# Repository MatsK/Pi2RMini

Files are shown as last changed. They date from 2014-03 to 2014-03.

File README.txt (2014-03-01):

Pi2RMini 
2013-2014 Logan Microelectronics

Small power switch for the Raspberry Pi. Free to use, modify, and distribute with proper attribution. This directory holds the current schematic and layout (Eagle v6.1.0), single layer PDF (not mirrored), code for ATTiny13 and Raspberry Pi, and older versions.

awjlogan@gmail.com
awjlogan.wordpress.com

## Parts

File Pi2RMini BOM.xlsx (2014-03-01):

Pi2RMini BOM file
Sch. # | Part | Package | Farnell Code | Price / 100 | Notes | Total ex. VAT | £2.241
C1 | 10u ceramic | 0805 | 1288204 | £0.066 |  | VAT | £0.448
C2 | 10u ceramic | 0805 | 1288204 | £0.066 |  | Total | £2.689
IC1 | ATtiny13 | SOIC8 | 1715519 | £0.360
IC2 | MCP1700 | SOT23 | 1296952 | £0.197 |  | Total parts
Q2 | 2N7002 | SOT23 | 2317616 | £0.020 |  | Total unique
Q1 | SQ2319ES | SOT23 | 1869886 | £0.320
USB | micro USB B | n/a | 1568026 | £0.480 | optional
LED1 | Bicolour LED | SOT23 | 2146479 | £0.174 | optional
R1 | 270R | 0805 | 2331788 | £0.006
R2 | 10K | 0805 | 2331808 | £0.006
R3 | 10K | 0805 | 2331808 | £0.006
R4 | 0R | jumper
R5 | 10K | 0805 | 2331808 | £0.006
R6 | 10K | 0805 | 2331808 | £0.006
R7 | 10K | 0805 | 2331808 | £0.006
R8 | 10K | 0805 | 2331823 | £0.006
ISP | 2x3 header | n/a | 1248132 | £0.230
FP | 2x3 header | n/a | 1248132 | £0.230
SW | switch | n/a | 9471731 | £0.038
R9 | 10K | 0805 | 2331808 | £0.006
D1 | LL4148 | miniMELF | 7355513 | £0.012 | optional

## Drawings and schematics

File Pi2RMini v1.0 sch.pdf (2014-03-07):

# 8 GND

A

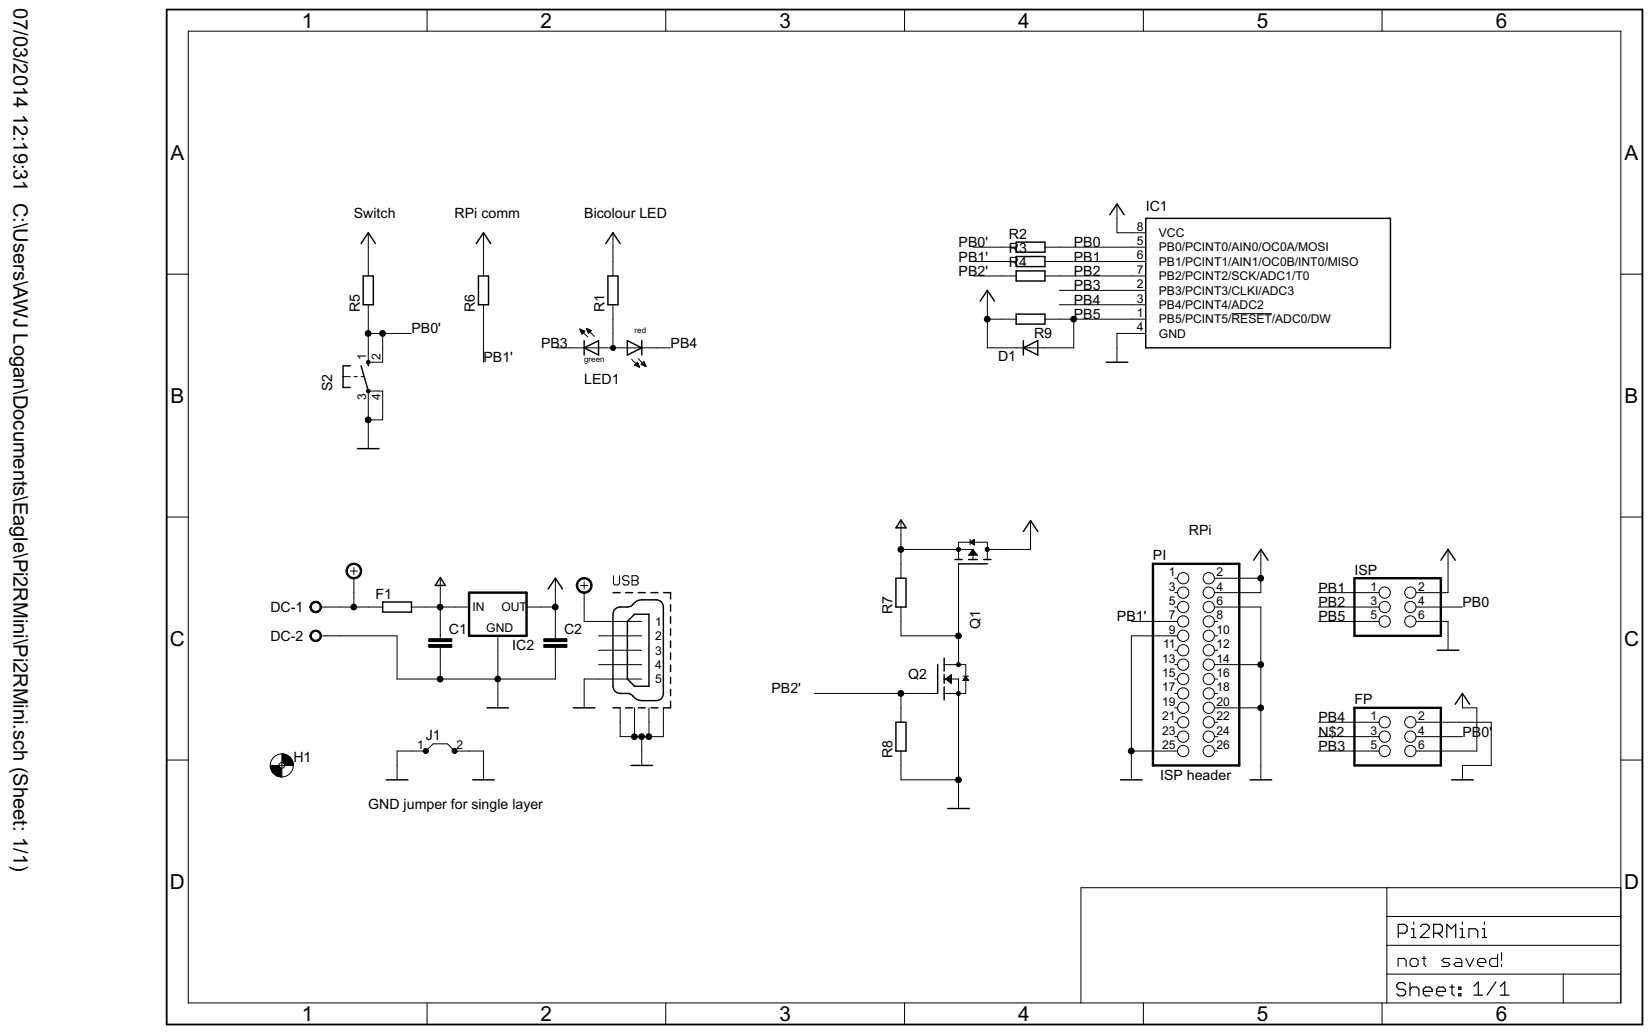
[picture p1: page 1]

07/03/2014 12:19:31 C:\Users\AWJ Logan\Documents\Eagle\Pi2RMini\Pi2RMini.sch (Sheet: 1/1)

GND jumper for single layer

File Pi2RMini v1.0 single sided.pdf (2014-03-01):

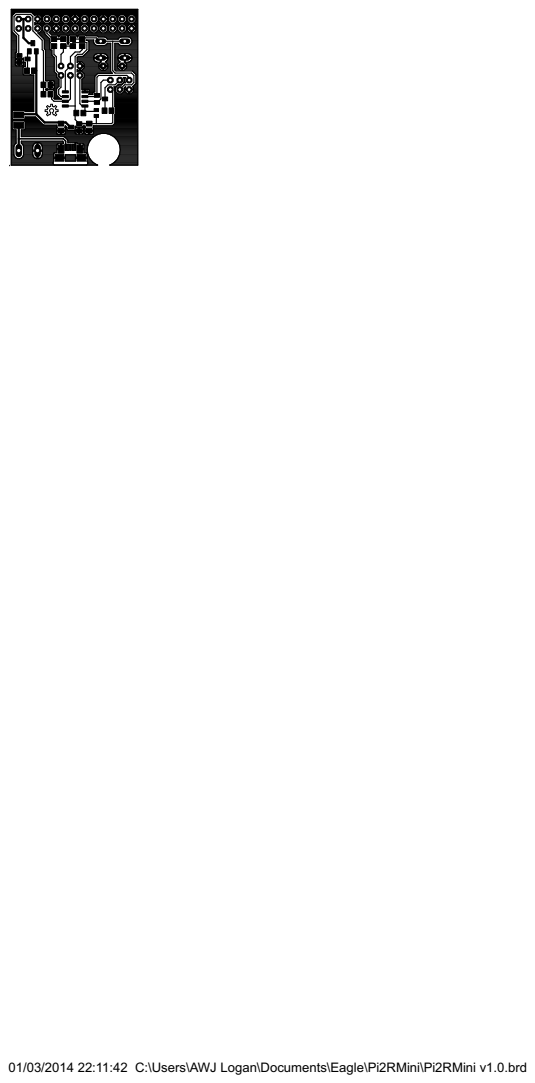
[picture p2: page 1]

01/03/2014 22:11:42 C:\Users\AWJ Logan\Documents\Eagle\Pi2RMini\Pi2RMini v1.0.brd

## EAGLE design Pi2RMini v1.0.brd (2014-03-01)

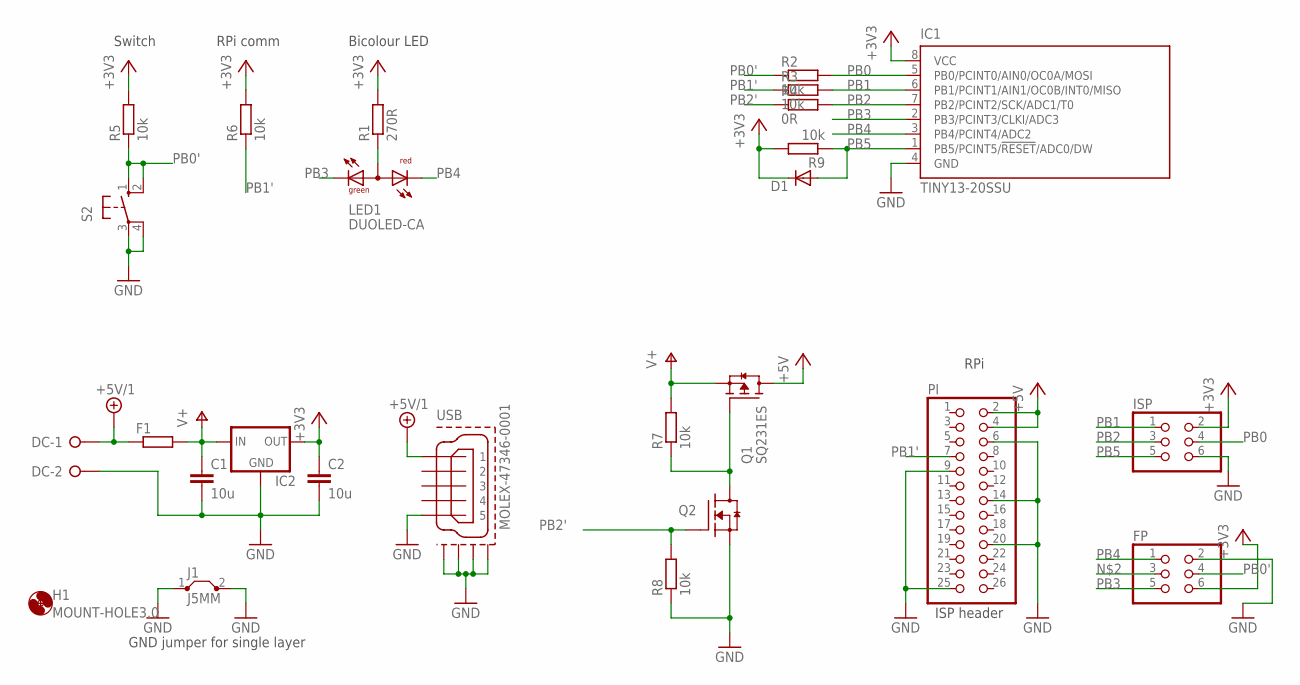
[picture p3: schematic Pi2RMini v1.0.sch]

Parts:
C1, C2: 10u; C0805
D1: DIODE-MICROMELF-R; MICROMELF-R
DC: W237-02P; W237-132
F1: R-EU_R1210; R1210
FP: PINHD-2X3; 2X03
H1: MOUNT-HOLE3.0; 3,0
IC1: TINY13-20SSU; 8S1
IC2: MCP1700TT; SOT-23
ISP: PINHD-2X3; 2X03
J1: J5MM; 05
LED1: DUOLED-CA; SOT-23
PI: PINHD-2X13; 2X13
Q1: SQ231ES; SOT-23
Q2: 2N7002; SOT-23
R1: 270R; R0805
R2, R3, R5, R6, R7, R8, R9: 10k; R0805
R4: 0R; R0805
S2: 10-XX; B3F-10XX
USB: MOLEX-47346-0001; MOLEX-47364-0001

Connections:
+3V3: C2.1, D1.C, FP.6, IC1.8 (VCC), IC2.2 (OUT), ISP.2, R1.2, R5.2, R6.2, R9.2
+5V: PI.2, PI.4, Q1.3 (D)
+5V/1: DC.1, F1.1, USB.1
GND: C1.2, C2.2, DC.2, FP.2, IC1.4 (GND), IC2.1 (GND), ISP.6, J1.1, J1.2, PI.6, PI.9, PI.14, PI.20, PI.25, Q2.2 (S), R8.1, S2.3, S2.4 (P1), USB.5, USB.GND1, USB.GND2, USB.GND3, USB.GND4
unnamed: FP.3, LED1.3 (A), R1.1
unnamed: Q1.1 (G), Q2.3 (D), R7.1
PB0: IC1.5 (PB0/PCINT0/AIN0/OC0A/MOSI), ISP.4, R2.2
PB0': FP.4, R2.1, R5.1, S2.1 (S), S2.2 (S1)
PB1: IC1.6 (PB1/PCINT1/AIN1/OC0B/INT0/MISO), ISP.1, R3.2
PB1': PI.7, R3.1, R6.1
PB2: IC1.7 (PB2/PCINT2/SCK/ADC1/T0), ISP.3, R4.2
PB2': Q2.1 (G), R4.1, R8.2
PB3: FP.5, IC1.2 (PB3/PCINT3/CLKI/ADC3), LED1.2 (CG)
PB4: FP.1, IC1.3 (PB4/PCINT4/ADC2), LED1.1 (CR)
PB5: D1.A, IC1.1 (PB5/PCINT5/!RESET!/ADC0/DW), ISP.5, R9.1
V+: C1.1, F1.2, IC2.3 (IN), Q1.2 (S), R7.2

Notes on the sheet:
Switch
RPi comm
Bicolour LED
GND jumper for single layer
ISP header
RPi

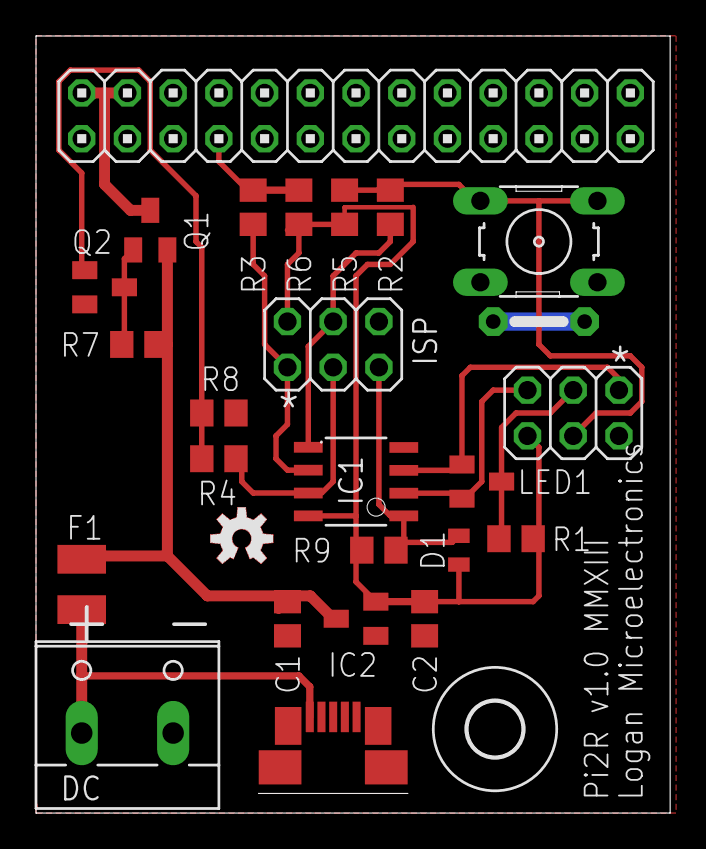
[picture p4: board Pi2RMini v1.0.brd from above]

Board: 2 copper layers, 35.2 x 43.2 mm, 26 parts (0 on the bottom side), 16 nets.

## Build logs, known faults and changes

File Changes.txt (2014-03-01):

Version 1.1
    ==== CHANGES ====
        - moved C1 left
        - enlarged mounting hole to 3.2 mm
        - turned power input 90° so on left hand edge
        - using internal pull ups
        - added separate red/green LEDs
        - changed to common cathode LED
        - removed R1, R4, R9
        
    ==== RESULTS ====

Version 1.0
    ==== RESULTS ====
        - position of C1 / IC1 ambiguous
        - R8 >> R4 [R4 necessary?]
        - red LED dominates green

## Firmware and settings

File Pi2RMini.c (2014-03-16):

/*
 * Pi2RMini.c
 *
 * Pi2R Mini device firmware for v1.0 boards
 * Logan Microelectronics 2013-2014
 * http://awjlogan.wordpress.com
 * https://github.com/awjlogan/pi2rmini
 *
 * Written in AVR Studio 5 for AVR GCC
 * Target: Atmel ATTiny13
 * 4.8 MHz internal osscilator / 8 = 600 kHz
 * Pins:	1	!RST					PB5
 *			2	Green LED				PB3
 *			3	Red LED					PB4
 *			4	GND		
 *			5	Switch					PB0
 *			6	RPi communication line	PB1
 *			7	RPi MOSET				PB2
 *			8	+3V3
 *
 * Fuse calculated:		69 FF (http://www.engbedded.com/fusecalc)
 * avrdude arguments:	-U lfuse:w:0x69:m -U hfuse:w:0xff:m
 * for: 4.8 MHz int osc, 14CK + 64 ms startup, CKDIV, no WDT, SPI enabled, !RST enabled, no BOD
 *
 * To change the startup, reset, and shutdown delays, alter lines with 'seconds = xx'. The TMR0 interrupt hits every
 * ~100 ms, so the seconds value should be 'delay in seconds x 10'. The variable 'flash' acts in the same way.
*/			

#define F_CPU		600000UL

#include <avr/io.h>
#include <avr/interrupt.h>
#include <util/delay.h>

// Status register definitions
#define	PI_ERROR	1
#define PI_ON		8
#define PI_OFF		16
#define BUTTON		32

#define PI_COMM		PINB1

// Pin assignments
#define SW			0x01
#define PI_FET		0x04
#define LED_G		0x08
#define LED_R		0x10

// common cathode status LED on/off
#define RED_OFF		PORTB &= ~(LED_R)
#define RED_ON		PORTB |= LED_R
#define GRN_OFF		PORTB &= ~(LED_G)
#define GRN_ON		PORTB |= LED_G

// Function prototypes
static void setup(void);
static void button(void);
static void reset(void);

// Global variables
static volatile uint8_t state = 0;
static volatile uint8_t flash = 0;
static volatile uint_least16_t seconds = 0;

int main(void)
{
	setup();
	state |= PI_OFF;
	RED_ON;
	GRN_OFF;
	
	// check status registers and respond
	while(1)
    {	
		if (state & BUTTON) {
			// disable PCINT while button press is handled
			PCMSK &= ~(1<<PCINT0);
			state &= ~(BUTTON);
			_delay_ms(50);					// debounce
			if (!(PINB & PINB0)) {
				button();
			}
			PCMSK |= (1<<PCINT0);
		}
		
		// flash red LED if in error state
		if (state & PI_ERROR) {
			if (!flash) {
				PORTB ^= LED_R;
				flash = 2;
			}
		}
	}	
}

static void button(void) {
	if (state & PI_OFF) {
		state = PI_ON;
		PORTB |= PI_FET;
		GRN_ON;
		RED_ON;
		
		// wait 60 secs for RPi to start up
		seconds = 600;
		while(PINB & (1<<PI_COMM)) {
			if (!seconds) {
				state |= PI_ERROR;
				GRN_OFF;
				return;
			}
		}
		RED_OFF;
		return;
	}
	
	if (state & PI_ON) {
		// check for forced reset - 4 s press
		seconds = 40;
		RED_ON;
		GRN_OFF;
		while (!(PINB & (1<<PINB0))) {
			// flash red/green
			if (!flash) {
				PORTB ^= (LED_G + LED_R);
				flash = 2;
			}
			// time up, reset!
			if (!seconds) {
				cli();
				reset();
				while(!(PINB & (1<<PINB0)));
				sei();
				return;
			}
		}
		
		// don't turn off in error state
		if (state & PI_ERROR) {
			RED_ON;
			GRN_OFF;
			return;
		}		
		
		// send shutdown signal, wait 10 secs for response
		RED_ON;
		GRN_OFF;
		DDRB |= (1<<DDB1);
		PORTB |= (1<<PINB1);
		_delay_ms(1);
		PORTB &= ~(1<<PINB1);
		_delay_ms(100);
		DDRB &= ~(1<<DDB1);
		PORTB |= (1<<PINB1);
		seconds = 100;
		while(PINB & (1<<PI_COMM)) {
			if (!seconds) {
				RED_ON;
				GRN_OFF;
				state |= PI_ERROR;
				return;
			}
		}
		
		// wait 30 secs, then shutdown
		GRN_ON;
		seconds = 300;
		while(seconds) {}
		reset();
		return;
	}
}

static void reset(void) {
	state = PI_OFF;
	PORTB = LED_R;
	DDRB = ((1<<DDB2)|(1<<DDB3)|(1<<DDB4));	
	return;
}

static void setup(void) {
	cli();
	
	// oscillator setup
	CLKPR = 0x80;	
	CLKPR = 0x03;
	
	// interrupt setup
	PCMSK |= 1 << PCINT0;	
	GIMSK |= 1 << PCIE;
	TIMSK0 |= 1 << TOIE0;
	
	// TMR0 setup
	// TCNT0 = 21 will give 0.1s count up time
	TCCR0A = 0;		
	TCCR0B = 0x05;	
					
	// PORTB setup
	MCUCR |= (1<<PUD);
	DDRB = ((1<<DDB2)|(1<<DDB3)|(1<<DDB4));	

	sei();
}

ISR(PCINT0_vect) {
	state |= BUTTON;
}

ISR(TIM0_OVF_vect) {
	if(flash) flash--;
	if(seconds) seconds--;
	TCNT0 = 21;					// reset for ~100 ms interval
}

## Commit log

2014-03-01 First version
    [Pi2RMini 1.0.brd, Pi2RMini 1.0.sch, Pi2RMini BOM.xlsx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]
2014-03-07 Added v1.0 schematic
